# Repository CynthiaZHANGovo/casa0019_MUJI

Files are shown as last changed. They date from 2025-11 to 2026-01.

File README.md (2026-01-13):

# SkySync_Transit

## Description

SkySync_Transit is a hybrid system combining **physical devices** and a **digital twin**, designed specifically to assist **UCL students** in planning their bus trips after classes. The system integrates **bus schedules**, **weather**, **walking times**, and **CE course timetable data** to provide real-time recommendations and visual feedback.

**Motivation:**  
UCL students often need to quickly decide which bus to catch after class based on their course schedule and weather conditions. SkySync_Transit was created to make commuting more intuitive, reducing stress and helping students make informed decisions.

**Why this project:**  
Instead of relying solely on apps or static timetables, SkySync_Transit combines physical interaction, course timetable data, and a digital dashboard, allowing users to instantly see bus recommendations, estimated walking times, and weather conditions tailored to their class schedule.

**Problem it solves:**  
Helps UCL students efficiently plan which bus to take after class, estimate walking times under different weather conditions, and visually understand the urgency of catching the next bus.

**What we learned:**  
- Integration of hardware (sensors, servo, LED, LCD) with APIs and MQTT data streams  
- Visualizing time-sensitive information using both physical pointers and a digital gauge dashboard  
- Combining CE timetable data with real-world commuting decisions  
- Building a digital twin that accurately mirrors physical device behavior  

---

## Table of Contents

- [Overview](#overview)
- [Physical Device](#physical-device)
- [Digital Twin](#digital-twin)
- [Gauge Dashboard Design](#gauge-dashboard-design)
- [Software & Data Interfaces](#software--data-interfaces)
- [Connection](#connection)
- [Usage](#usage)
- [Credits](#credits)
- [GitHub Repository Structure](#github-repository-structure)
- [License](#license)

---

## Overview

SkySync_Transit allows UCL students to select a bus route using a rotary knob. Based on the selected bus, current weather, walking distance, and class schedule, the system calculates estimated travel time, recommends the next best bus, and provides visual feedback through an LCD display, a physical pointer, and LED strip. All data is synced via MQTT and APIs.

---

## Physical Device

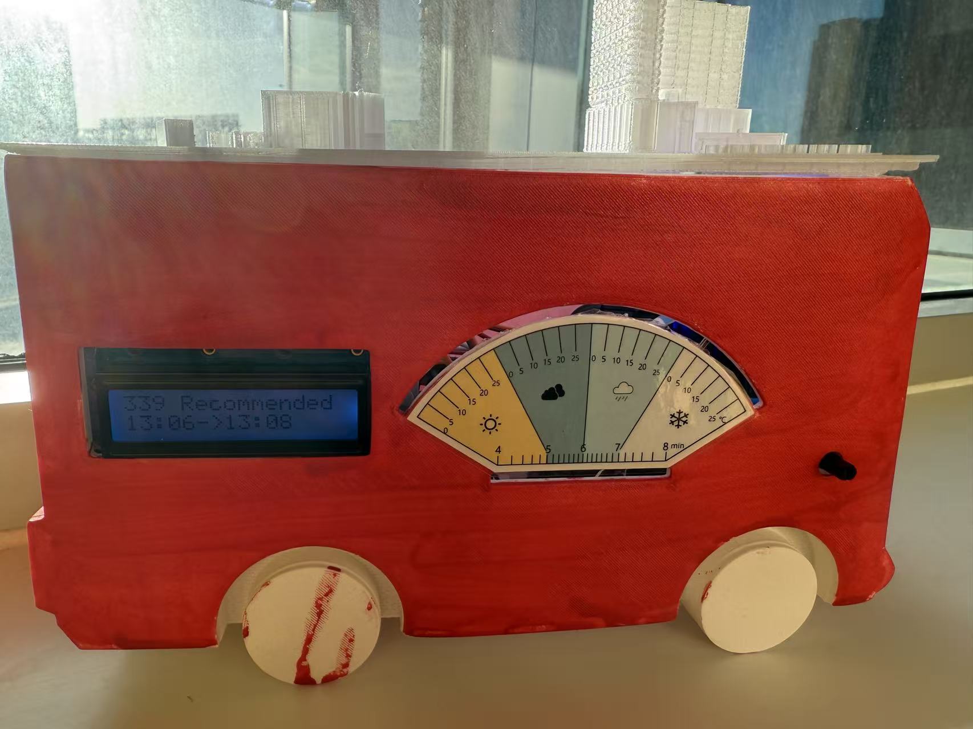
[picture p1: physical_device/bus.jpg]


The physical device provides a tangible, real-time representation of weather conditions, walking time, and bus urgency. It includes:

### Hardware Components

- **ESP8266 Microcontroller**  
  - Core controller for all hardware components  
  - Connects to Wi-Fi to access APIs and MQTT topics  
  - Handles sensor input, servo output, LED control, and data processing  

- **Rotary Angle Sensor v1.2**  
  - Used to select the bus number (108 or 339)  
  - Automatically detected on startup, triggering timetable API requests  

- **MG90S Servo Motor**  
  - Drives the analog-style pointer  
  - Pointer position corresponds to weather condition, temperature segment, and calculated walking time  

- **LCD Display (Grove-LCD RGB Backlight)**  
  - Shows estimated walking time based on weather + temperature  
  - Displays bus timetable returned from the API  
  - Highlights the recommended bus based on UCL CE class schedule  

- **LED Strip (BTF 5V 60LED/m)**  
  - Uses color gradients to visualize urgency of catching the next bus  
  - Updates dynamically based on timetable and walking-time calculations  

- **3D-Printed Structure**  
  - Two-print materials used: opaque + translucent  
  - Represents walking route from One Pool Street to the destination  
  - Houses the gauge instrument panel (print + lamination)

---

## Digital Twin

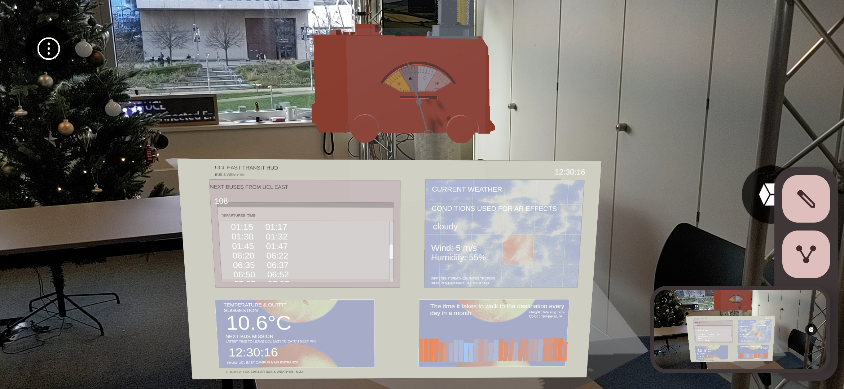
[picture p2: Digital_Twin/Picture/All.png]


The digital twin mirrors the behavior of the physical device and provides **more detailed data**:

- Digital gauge dashboard showing the same segments, zones, and walking-time pointer  
- Displays more bus options than the physical device  
- Shows detailed weather information and suggestions for travel  
- Allows users to **scan different images** to switch between bus lines  
- Provides a richer monitoring interface for debugging and live demonstration  

---

## Gauge Dashboard Design

The **gauge dashboard** is the visual system used both in the physical device and digital twin.

### Zones & Segments

- Weather zones (left → right): **Sunny → Cloudy → Rainy → Snowy**  
- Each zone has **6 temperature segments**:

| Segment | Temperature (°C) |
|---|---|
| 0 | temp ≤ 0 |
| 1 | 0 < temp ≤ 5 |
| 2 | 5 < temp ≤ 10 |
| 3 | 10 < temp ≤ 20 |
| 4 | 20 < temp ≤ 25 |
| 5 | temp > 25 |

- Total walking time range: **4–8 minutes**  
- Each segment = **10 seconds**  
- Example: Rainy + 8.8°C → zone 3, segment 3 → 380 sec → 6.33 minutes  

Both APIs and MQTT provide pre-calculated results:
- Weather  
- Temperature  
- Walking time (seconds + minutes)  
- Zone index  
- Segment index  
- Final pointer target

---

## Software & Data Interfaces

### Bus Timetable API
- **Endpoints**:  
  - `http://10.129.111.26:3000/api/timetable/108`  
  - `http://10.129.111.26:3000/api/timetable/339`  
- Returns full-day schedules for selected bus  
- Includes times for **Aquatic Center** and **Stratford Station**  
- Provides **recommended next bus** based on CE timetable (class ends at 13:00)  
- **MQTT topics** available for live streaming (use lowercase *qingshan*)

### Weather & Walking Time API
- `http://10.129.111.26:3000/api/current-walk`  
- Returns temperature, weather, pointer zone/segment, and walking time  

### CE Course Timetable Integration
- Ensures bus recommendation fits UCL students’ real class schedules  
- The system chooses the next bus *after* class end time

---

## Connection

1. Connect all hardware components.  
2. Connect to the UCL classroom network (required for API access).  
3. Install libraries for sensors, servo, LED strip, LCD display, and MQTT.  
4. Clone the repository to the ESP8266.  
5. Configure MQTT topics (`qingshan/...`).  
6. Power the device to begin automatic detection and data fetching.  

---

## Usage

1. Power on the system.  
2. Select bus route via the rotary knob.  
3. Device fetches timetable via API or MQTT.  
4. Weather and walking data are retrieved from the walking API.  
5. System calculates estimated walking time and bus recommendation.  
6. Data is displayed via LCD, pointer gauge, and LED urgency indicator.  
7. Digital twin shows additional details for debugging or demonstration.
---

## System Flow

Rotary Knob -> Detect Bus Number -> Fetch Bus Timetable (API/MQTT) 
             -> Fetch Weather & Walking Time -> Calculate Estimated Travel Time 
             -> Physical Gauge + LCD + LED Output 
             -> Digital Twin Dashboard Rendering

---

## GitHub Repository Structure

- **[Backend_code_section](https://github.com/CynthiaZHANGovo/casa0019_MUJI/tree/main/Backend_code_section)**  
  Backend APIs for bus timetables, weather data, walking-time calculation, and CE timetable logic.

- **[physical_device](https://github.com/CynthiaZHANGovo/casa0019_MUJI/tree/main/physical_device)**  
  Coding documents of physical device.

- **[Digital_Twin](https://github.com/CynthiaZHANGovo/casa0019_MUJI/tree/main/Digital_Twin)**  
  Files of digital twin.

- **[Scripts](https://github.com/CynthiaZHANGovo/casa0019_MUJI/tree/main/Scripts)**  
  C# scripts for API handling, MQTT communication, gauge animation, and UI logic.

- **[Shell](https://github.com/CynthiaZHANGovo/casa0019_MUJI/tree/main/Shell)**  
  3D-printable files for the physical enclosure and gauge mechanism.

- **[Sensors_Testing](https://github.com/CynthiaZHANGovo/casa0019_MUJI/tree/main/Sensors_Testing)**  
  Sensor testing code and calibration references.

- **[Documents](https://github.com/CynthiaZHANGovo/casa0019_MUJI/tree/main/Documents)**  
  Project notes, meeting minutes, and early design concepts.

---

## Credits

* Project Team Members:

  * [Qingshan Luo](https://github.com/malus-eng)
  * [Xinyi Zhang](https://github.com/CynthiaZHANGovo)
  * [Yidan Gao](https://github.com/gydgzh)
  * [Zihang He](https://github.com/xms12138)

---

## License

This project is licensed under the [MIT License](https://choosealicense.com/licenses/mit/).

---

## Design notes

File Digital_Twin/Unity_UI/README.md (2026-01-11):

# SkySync_Transit

## Work Division Agenda

**Course:** CASA0019: Sensor Data Visualisation (25/26)

**Total length:** \~2000 words (±10%)

---

## 1. Front Page & Administrative Info（≈150 words）

- Project Title: _SkySync_Transit_

- Course name & academic year

- Group members（姓名 + GitHub username）

- GitHub repository link（可访问）

- 简短 project tagline（1–2 句）

---

## 2. Project Context & Motivation

SkySync_Transit was developed for UCL students when making commuting decisions immediately after class. Many students regularly travel to Stratford and surrounding areas using bus services. These decisions are often time-sensitive, as students need to leave shortly after a class ends in order to select an appropriate bus. Missing a bus may lead to additional waiting time or a less efficient journey, particularly during busy periods. This highlights the need for clearer and more immediate representations of travel-related information (Batty, 2013).

The project focuses on the integration of bus timetable data, real-time weather conditions, and walking time estimates, as these factors jointly influence commuting decisions but are rarely considered together in an intuitive manner (Ma et al., 2019). While existing mobile applications provide access to such information, they often require active searching and increased cognitive effort from users, particularly in time-constrained situations (Aliannejadi et al., 2019). SkySync_Transit addresses this gap by combining these datasets into a single, coherent system that supports faster decision-making through visual and physical feedback.

---

## 3. System Overview & Design Concept（≈250 words）

### 3.1 Physical System

The physical part of SkySync_Transit is designed as a self-contained, real-time indicator of travel conditions. An **ESP8266 microcontroller** forms the core of the system, reading inputs from temperature, humidity and gas sensors as well as the rotary angle sensor that selects the active bus route (108 or 339). It connects to Wi-Fi to fetch live timetables and weather data, combines these with local sensor readings, and computes key parameters such as current conditions, estimated walking time and a recommended bus. These values are published via a small set of **MQTT topics**, which are subscribed to by the servo motor, LED strip and LCD display. In this way, the pointer, backlit display and colour-coded LEDs act as an analogue “dashboard” that visualises bus urgency and walking time using the same underlying logic. The physical system is therefore responsible for sensing, decision-making and embodied feedback in the classroom.

### 3.2 Digital Twin System

The digital part of SkySync_Transit is implemented as an AR **digital twin** in Unity. A lightweight backend exposes the same information used by the ESP8266 through RESTful **APIs**, including timetable endpoints for routes 339 and 108 and a `current-walk` style endpoint that wraps the weather-dependent walking-time model. Unity scripts such as `BusAPIManager` and `WeatherAPIManager` call these APIs, deserialize JSON into typed data models, and update the **TransitHubCanvas** interface, which contains panels for “NEXT BUSES FROM UCL EAST”, current weather, temperature and outfit suggestion, and data visualisation. The digital twin mirrors the behaviour of the physical gauge but is easier to modify, scale and debug, for example by testing new layouts or visual encodings without changing the hardware. Together, the MQTT-driven device and API-driven AR interface form a single system where both physical and digital views are always consistent and based on the same data.

---

## 4. Physical Device Design & Implementation

### 4.1 Hardware Design

The physical device of SkySync_Transit provides a tangible, real-time representation of weather conditions, estimated walking time, and bus urgency.
An **ESP8266 microcontroller** is used as the main controller for the system. It connects to Wi-Fi to access external APIs and MQTT topics, processes incoming data, and controls all input and output components, including sensors, the servo motor, LED strip, and LCD display.
User input is handled through a **Rotary Angle Sensor v1.2**, which allows users to select between bus routes (e.g. 108 or 339). The selected route is detected automatically and triggers requests to the corresponding bus timetable API.
A **MG90S servo motor** drives an analog-style pointer on the gauge interface. The pointer position reflects a combination of weather conditions, temperature segments, and calculated walking time, providing a quick visual indication of travel conditions.
A **Grove LCD RGB Backlight display** presents estimated walking time and bus timetable information retrieved from the API, and highlights the recommended bus based on the UCL CE course timetable. In addition, a **BTF 5V LED strip (60 LEDs/m)** visualises the urgency of catching the next bus using colour gradients that update dynamically according to timetable and walking-time calculations.

### 4.2 3D-Printed Structure and Gauge Panel

The 3D-printed structure has two main parts. The **transparent top** allows the LED strip to display the walking route to the destination, and incorporates a model of **One Pool Street**, combined with site data adapted from **CADMAPPER**, to ensure spatial accuracy. The second part is a custom-built model of a **classic London bus**, painted in red, which serves as a tangible reference for the selected bus route. The opaque base was designed with consideration for **sensor placement and component relationships**, ensuring stable integration of the hardware.

The **gauge instrument panel** is integrated into this structure, combining printed graphics and lamination to create a clear and durable interface. It visualizes estimated walking time using a combination of weather zones—Sunny, Cloudy, Rainy, and Snowy—and corresponding temperature segments. A servo-driven pointer, LED strip, and LCD display work together to convey time-sensitive information intuitively, allowing users to quickly perceive walking time and bus urgency. For example, Rainy conditions at 8.8°C correspond to a moderate walking time of approximately 6.33 minutes.

### 4.3 Data Visualisation Logic (Physical)

The rotary angle sensor is wired to the ESP8266’s A0, where its ratiometric voltage output is sampled and converted into discrete control state. The Grove RGB LCD shares the controller’s I²C bus (SDA/SCL), while enabling dual control of text and backlight through the same serial channel. The MG90S servo is attached to a PWM-capable pin so that duty-cycle modulation directly defines its mechanical output angle. 

The WS2812 LED strip is driven from a single digital pin with microsecond-scale timing accuracy. Because Wi-Fi, MQTT parsing and GPIO servicing run concurrently on the ESP8266, update jitter is mitigated by sequencing LED writes against network activity. 

The pointer is driven by an MG90S micro servo controlled by the ESP8266. Real-time weather and temperature data are first processed in the backend and discretised into **24 weather–temperature zones** on the dial (from sunny and mild on the left to snowy and harsh on the right). The backend sends the index of the active zone as an integer `segmentIndex` via MQTT.

On the physical gauge, only the calibrated arc between approximately **33° and 147°** is used. However, the firmware positions the pointer at the centre of each zone rather than at the boundary, producing a smoother, more readable pointer distribution. This 114° span is divided into 24 equal zones, and the pointer is positioned at the **centre of each zone**, which yields an effective step of about **4.25° per segment**. This mapping is hard-coded in the firmware as: 

                                                            **angle = 180° − 4.25° × segmentIndex.**

After clamping the result to the physical dial range, the ESP8266 outputs the corresponding PWM signal to the MG90S, moving the pointer cleanly to the selected weather–temperature region. Furthermore, each pointer movement first returns to the leftmost position before repositioning. So in the end, we obtained such a complete physical model.

UI

## 5. Digital Twin & Dashboard Design（≈300 words）

## 5.1 Digital Twin Interface

The SkySync_Transit digital twin is implemented in Unity as an AR screen based on a **World Space Canvas**. The main UI root, **TransitHubCanvas**, follows a layout first prototyped in Figma, with four panels: “NEXT BUSES FROM UCL EAST”, a temperature and outfit suggestion panel, a current weather panel, and a reserved data-visualisation area. During early development, random values were injected into these panels to test bindings and interactions before the real APIs were connected. 

Live data is then provided by “BusAPIManager” and ”WeatherAPIManager“, which call the timetable and current-walk style endpoints, deserialize the JSON into typed models (from APIDataModels), and update TextMeshPro fields in the bus, temperature and weather panels. 

To support both routes within one interface, “MainContent” contains two structurally identical bus panels, **`BusPane339`** and **`BusPane108`**, which share the same layout but are bound to different timetable data. Weather and temperature modules remain permanently active, while simple visibility logic switches between the two bus panels so that scanning 339 or 108 selects the corresponding route without duplicating the rest of the UI. 

## 5.2 Physical Device Synchronisation & Deployment

 To match the physical device and avoid overwhelming the camera view, the ”TransitHubCanvas“ Rect Transform is uniformly scaled down (e.g. all axes ≈ 0.0005), keeping proportions consistent in AR , and ARCore enabled in XR Plug-in Management, allowing the digital twin to run on Android phones alongside the hardware system.

## 5.3 Image Recognition

 Image recognition is implemented with AR Foundation. A reference image library, “BusRoutesImageLibrary”, stores the printed markers **`QR_339`** and **`QR_108`** with their physical sizes and is assigned to “ARTrackedImageManager” on the XR Origin. A dedicated controller, “BusQRImageController”, listens to “trackedImagesChanged”, positions and rotates “TransitHubCanvas” so that the UI stands upright and floats slightly in front of the detected marker, and then toggles BusPane339 or BusPane108 based on “referenceImage.name”, while leaving the weather and temperature panels unchanged.

## 5.4 Data synchronization and rendering

We use MQTT to fetch backend data, with the lower HUD panel driven entirely by real-time streams to stay synced with the physical system. The system subscribes to three topics — current weather and travel advice, route-specific bus recommendations, and ~30 days of walking-history data. Payloads are received through an M2MQTT client, parsed into strongly typed objects via JsonUtility, and safely handed off to the Unity main thread using simple state flags, since MQTT callbacks execute in the background.

To provide long-term insight rather than momentary status, the data-visualisation panel procedurally generates UI elements at runtime. A bar-chart system instantiates prefabs, scales them according to walking duration, and interpolates colour based on average temperature, converting raw telemetry into compact visual patterns.

Text-based displays are equally data-driven. The bus timetable now uses a three-column format (London Aquatics → Stratford City → recommendation), improving readability without modifying the source format. All UI panels refresh through event-driven logic so that each JSON packet actively updates the interface in real time rather than merely replacing placeholder values.

## 5.5 Realization of the Augmented 3D Digital Twin Model

Digital twins are not only reflected in the interface data layer but also achieved by placing a corresponding 3D bus model in the AR environment. The vehicle's onboard model from the physical device is imported into Unity as a prefab and acts as a child object of the detected QR code image. It automatically inherits the QR code's spatial position and orientation, thus appearing as a fixed object in the real-world scene and moving naturally with the user's viewpoint.

This virtual model is dynamically driven by real-time MQTT data. Unity subscribes to walking status topics and parses messages, extracting the segmentIndex and mapping it to a specific angle to control the rotation of the instrument panel pointer. The control script records the model's basic posture and overlays calculated offsets to ensure the animation is always geometrically aligned with the model. Pointer movement is smoothed using interpolation to avoid jumps and present continuous, natural state changes. We use the same dashboard as the physical system to ensure the pointer's position in the AR scene is consistent with the physical system.

This process forms a real-time feedback loop. When data is updated on the MQTT server, the pointer on the bus in the AR environment is updated simultaneously, allowing users to intuitively perceive changes in external information within the AR scene. By binding the model to an image target, scaling it appropriately, and performing simple visual customizations, we have constructed such a complete digital twin.

UI

---

## 6. Software, Data & Technologies

The data transmission portion of this project primarily relies on the MQTT protocol to transmit signals to the assembled electronic devices and on the API to transmit data to the digital twin system. The project mainly established three MQTT topics for devices to subscribe to: the timetables for bus routes 339 and 108, and the current London temperature and estimated walking time to the station. The API also provides the same three types of data. Using these three datasets, the digital twin and devices can effectively acquire data and display it clearly and efficiently.

More precisely, the data in the project mainly comes from publicly available data on authoritative websites. The timetable information for bus routes 339 and 108 is entirely sourced from the TFL website. Additionally, the London weather and temperature information is obtained from the Open-Meteo website, ensuring overall accuracy and reliability (Paudyal, Shakya and Upadhayaya, 2025). The data printed in this project is formatted as shown in the image below.
<p align="center">
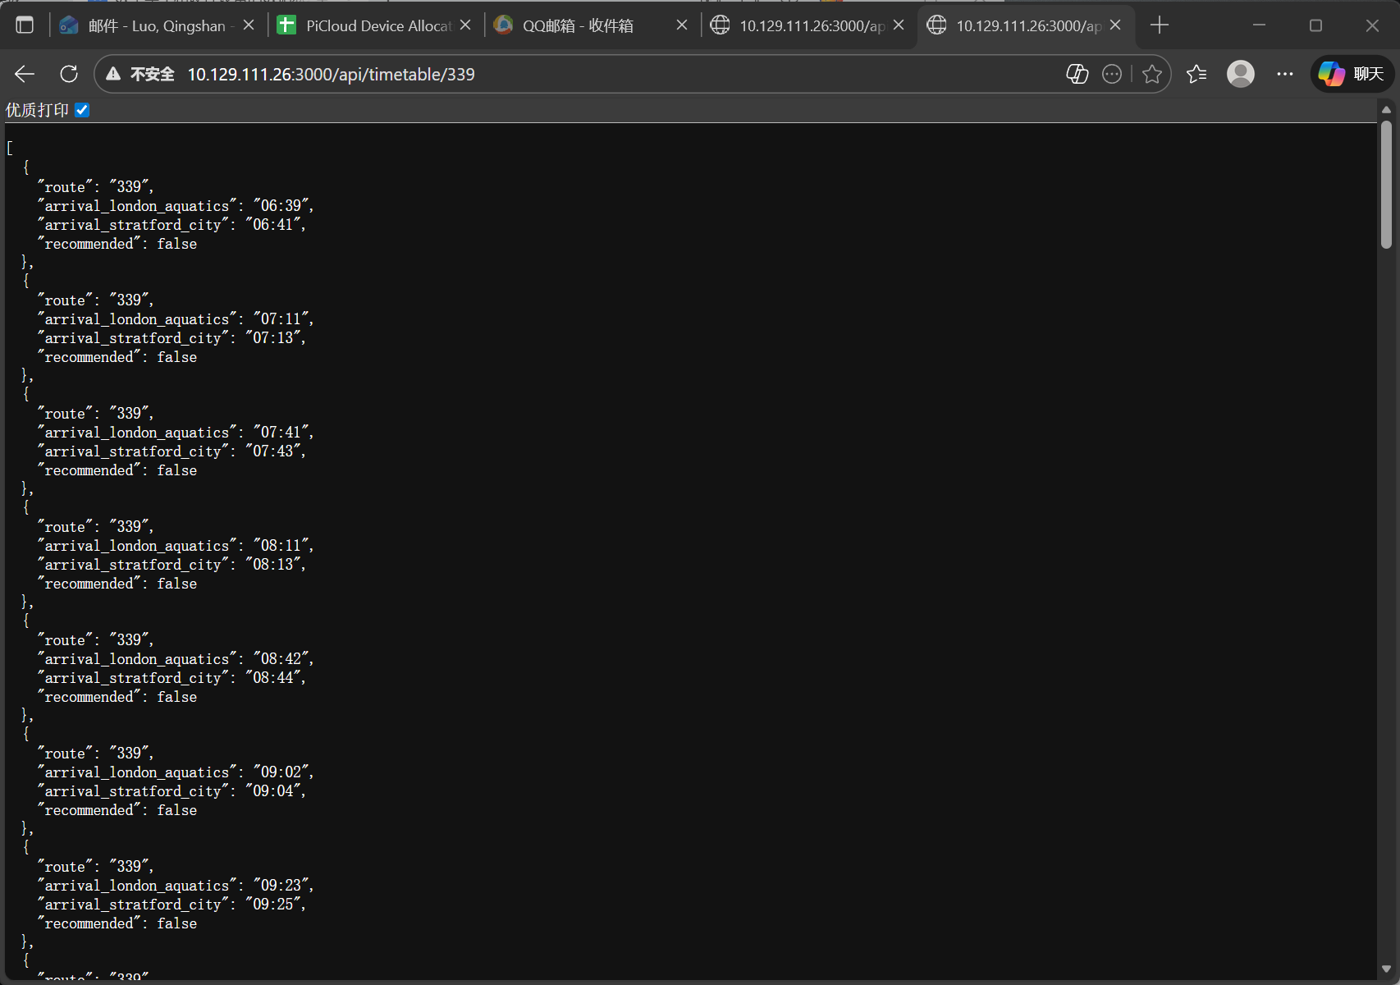
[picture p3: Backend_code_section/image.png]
  
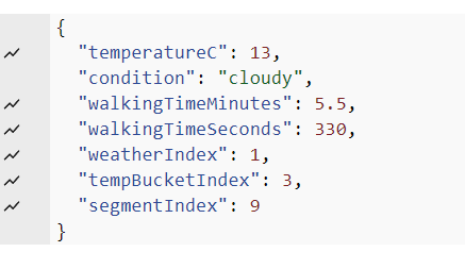
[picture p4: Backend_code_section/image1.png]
  
</p>

For timetables, the first line prints the bus number for easy identification during calls. The second and third lines print the arrival times at London Aquatics and Stratford City stations, respectively. The fourth line indicates whether the bus is recommended. This line helps users choose recommended buses. The project combines the daily class dismissal times and student arrival times at the station to calculate which bus will arrive first after students reach the station and recommends that bus.

For weather-related MQTT topics and APIs, the first line prints the current temperature in London. The second line prints the current weather in London. The third and fourth lines print the walking time from the school to the station in minutes and seconds, respectively. This time is mainly determined by a specific formula based on the current weather and temperature (Dunn, Shaw and Trousdale, 2012). Lines five, six, and seven mainly guide the pointer movement to accurately indicate the estimated time.

### 6.3 Tools & Platforms

**Arduino / ESP8266** serves as the core controller for the physical device, handling sensor inputs, LED and servo outputs, and communication with APIs and the MQTT broker.  

- Unity / dashboard tools

- GitHub as documentation & reproducibility platform

---

## 7. Contributions（≈200 words）

-        *   Hardware & electronics

         *   Software & API integration

         *   Digital twin & UI

         *   Fabrication & physical design

         *   Documentation & GitHub management

***

## 8. What Worked & What Didn’t & Future Improvements

Overall, the project largely achieved its initial goals. The team enabled students to visually see the bus schedules they should take after class, use a pointer to determine the current weather and estimated travel time, and select specific bus routes using a knob. 

However, some goals were not achieved. Initially, the team planned to display all bus information on the hardware in a scrolling display, but they discovered that the processor's storage was insufficient to load the entire schedule, forcing them to abandon this feature (Hercog et al., 2023). Furthermore, the box's structure hindered the display of current weather and walking time. Firstly, the box itself was not large enough while the pointer was slightly long, causing it to touch the left wall of the box when pointing to the far left. Secondly, the pointer was designed inside the box, requiring a slot to be clearly visible, which was inconvenient, making it difficult for users to clearly observe the pointer's direction most of the time. 

To address these shortcomings, future updates to the project will focus on two aspects: firstly, using a more powerful processor with more storage to ensure the display of the entire timetable and more other data. In addition, the team will also consider redesigning the entire box structure to ensure that the box structure itself does not conflict with the pointer's path, or designing the pointer as an external structure to ensure that users can clearly observe the pointer's position.

## 10. Repository Structure & Reproducibility（≈150 words）

- GitHub repo 结构说明

- Code / Unity / STL / diagrams

- How to reproduce the project

- Reference & citation strategy

---

## 11. Conclusion（≈100 words）

- 项目价值总结

- 与 CASA0019 learning outcomes 对应

- Physical data visualisation 的意义

## References

Aliannejadi, M., Harvey, M., Costa, L., Pointon, M. and Crestani, F. (2019) ‘Understanding mobile search task relevance and user behaviour in context’, in *Proceedings of the 2019 Conference on Human Information Interaction and Retrieval*. New York: ACM, pp. 143–151. https://doi.org/10.1145/3295750.3298953

Batty, M. (2013) *The new science of cities*. Cambridge, MA: MIT Press.

Dunn, R. A., Shaw, W. D. and Trousdale, M. A. (2012) ‘The effect of weather on walking behavior in older adults’, *Journal of Aging and Physical Activity*, 20(1), pp. 80–92.

Hercog, D., Zivkovic, M., Belanovic, I., Donlagic, D. and Gams, M. (2023) ‘Design and implementation of ESP32-based IoT devices’, *Sensors*, 23(15), p. 6739. https://doi.org/10.3390/s23156739

Ma, J., Chan, J., Ristanoski, G., Rajasegarar, S. and Leckie, C. (2019) ‘Bus travel time prediction with real-time traffic information’, *Transportation Research Part C: Emerging Technologies*, 105, pp. 536–549. https://doi.org/10.1016/j.trc.2019.06.015

Paudyal, K. R., Shakya, R. and Upadhayaya, J. (2025) ‘Spatiotemporal PM2.5 estimation in Kathmandu using deep learning with OpenMeteo and NASA MERRA-2 data: Performance benchmarking against a machine learning model’, *International Journal on Engineering Technology*, 3(1), pp. 36–45.

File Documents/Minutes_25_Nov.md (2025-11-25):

# Meeting Minutes  – Transport
**Date:** 25-Nov-2025  

## 1. Theme & Overall Idea

- We decided to go with the **Transport** theme.
- After chatting with **Andy** and **Valerio**, the plan is:

  - Use a **timetable API** (bus/train/car) + **weather API**.  
  - Consider **walking time** from **UCL East campus → tube station**.  
  - Combine with the **course timetable** so the system:
    - Knows **when class ends**.
    - Suggests the **best departure** and **a couple of alternatives** before/after.
  - “Highlight” idea:  
    - Use **weather** (rain, wind, etc.) to adjust how long it takes to walk from campus to the station.  
    - Visualise this nicely (both physically and digitally).

---

## 2. Physical Device

The physical device will **visualise vehicle timetables**. Planned components:

- **Vehicle model box**
  - A physical model representing the bus

- **Gear motor + progress bar**
  - A mechanical progress bar driven by a motor, showing journey progress.

- **Simple LED display**
  - Displays key info like:
    - Weather info 
    - Route / line chose
    - Minutes left
    - ...

- **Route switch button**
  - Press to switch between routes (different lines).

---

## 3. Digital Twin

We’ll have **two main 2D screens**:

1. **Weather screen**
   - Shows:
     - Temperature  
     - Rainfall level  
     - UV index  
     - Wind strength
     - ...
   - Also gives simple suggestions like:
     - “Bring an umbrella.”  
     - “Wear a coat.”  
     - “Windy – leave a bit earlier.”

2. **Timetable and journey panel**
   - Displays:
     - Class end time  
     - Relevant transport line(s)  
     - Estimated time needed to walk from UCL East campus to the tube station (adjusted by weather)  
     - The **best** departure option and **alternative options** (earlier and later services)  
   - If time allows, this panel may be enhanced with the **MapBox** to visualise the route and position.

---

## 4. Work Distribution For This Week

- **Yidan Gao**  
  - Build a basic **Unity** setup for the digital twin (two panels: weather + timetable).

- **Qingshan Luo**  
  - Try using **MKR1010 WiFi** to connect to the **timetable API** and **weather API**.

- **Zihang He & Xinyi Zhang**  
  - Build the **gear motor–driven progress bar** for the physical device.

---

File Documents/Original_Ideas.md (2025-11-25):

| Theme | Possible angles | Physical device | Digital twin |
|---|---|---|---|
| Plant wellbeing / digital gardener | - Monitor temperature, soil moisture, CO₂, light level<br>- Publish raw sensor values and derived metrics over MQTT | - LED ring (colour encodes type of issue)<br>- Servo-driven base shell<br>- Small LED display screen or analogue-style gauge | - Time-series chart component<br>- UI gauge for key metrics<br>- Optional 3D plant model<br>- Overall health scale and leaf colour<br>- Toggle which metric the chart displays (same as device controls) |
| Transports | - Vehicle timetable (bus / train) combined with weather API<br>- Include walking time to the station<br>- Provide alternative route options<br>- Integrate with course timetable (e.g. UCL → tube station, CE timetable)<br>- Visualise vehicle times with a light-up model | - Small physical route model with LEDs indicating next departures and routes | - Two main panels: (1) weather information, (2) timetable information<br>- Visualisation of the journey from CELAB → Stratford<br>- (If time) map-based view (e.g. MapBox-style map) |
| Healthcare (Fitness / Rehab game) | - Exercises: squats, walking, jump-rope, hand swings<br>- Provide calorie and other feedback<br>- Use BMI, pulse, and limb motion (ankle / wrist / hand)<br>- Estimate calories from time + user input (height / weight) + orientation / motion sensors | - Battledore / wand-like device<br>- Worn on ankle / wrist / hand to track motion<br>- LEDs for feedback (e.g. success, intensity, rhythm, heart-rate zone cue) | - AR avatar or pet reacting to the user’s motion and performance (e.g. cheering, growing, changing appearance based on activity and adherence) |

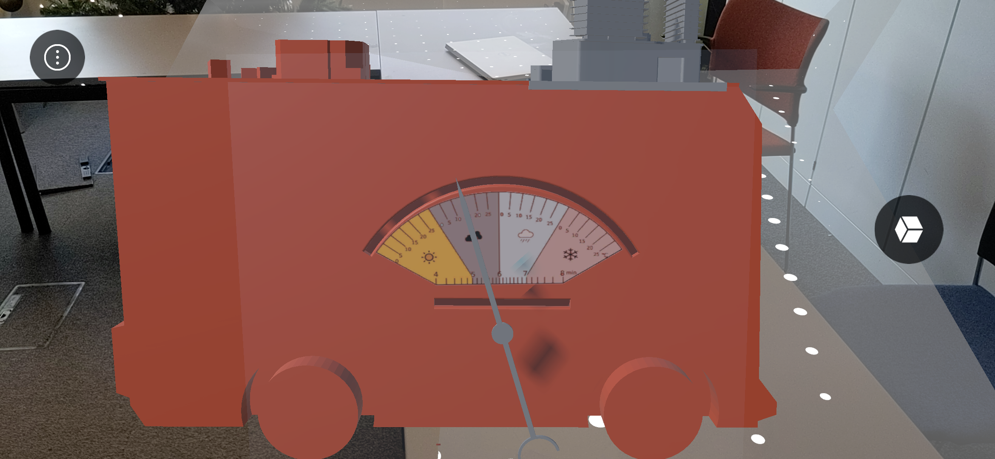
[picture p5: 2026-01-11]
Digital_Twin/Picture/Bus.png

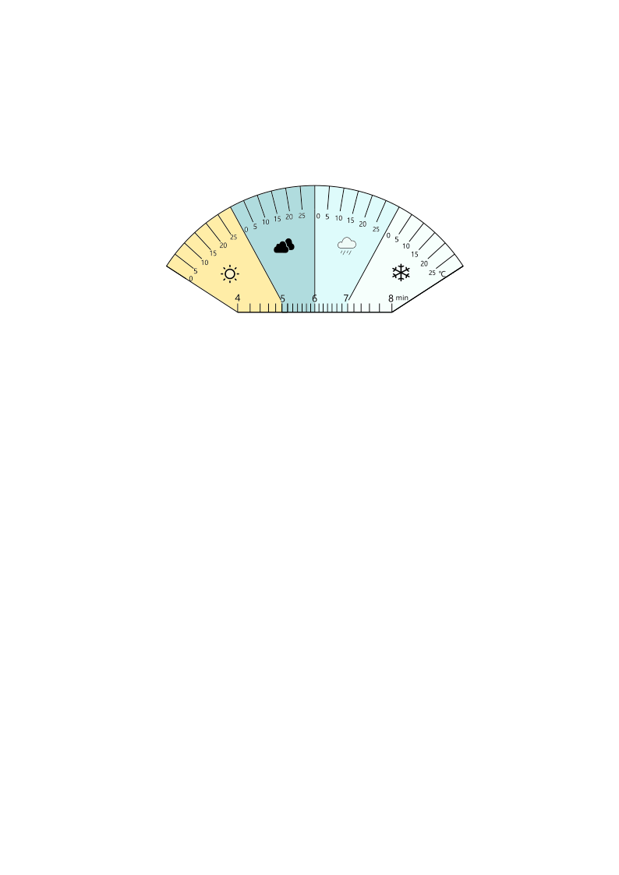
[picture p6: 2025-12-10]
Digital_Twin/Model/gauge.png

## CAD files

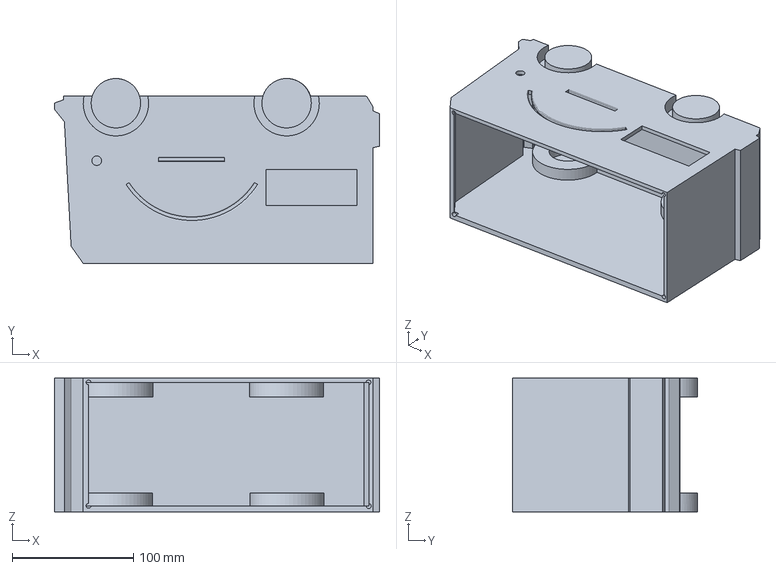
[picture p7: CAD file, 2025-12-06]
physical_device/Shell/car Model.3mf
268.4 x 152.8 x 110.7 mm

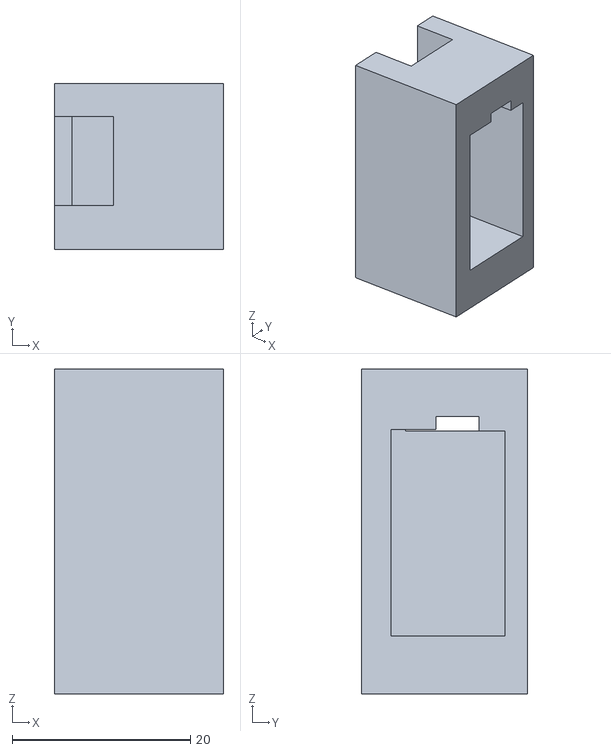
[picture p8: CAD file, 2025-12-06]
physical_device/Shell/ServoHolder2.0.stl
19.0 x 18.6 x 36.5

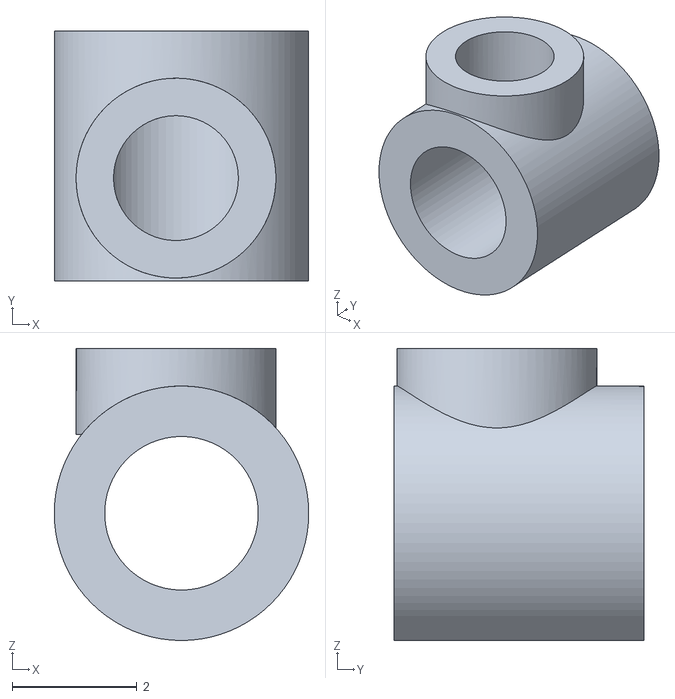
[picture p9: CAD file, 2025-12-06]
physical_device/Shell/ring3.0.stl
4.08 x 4.00 x 4.68

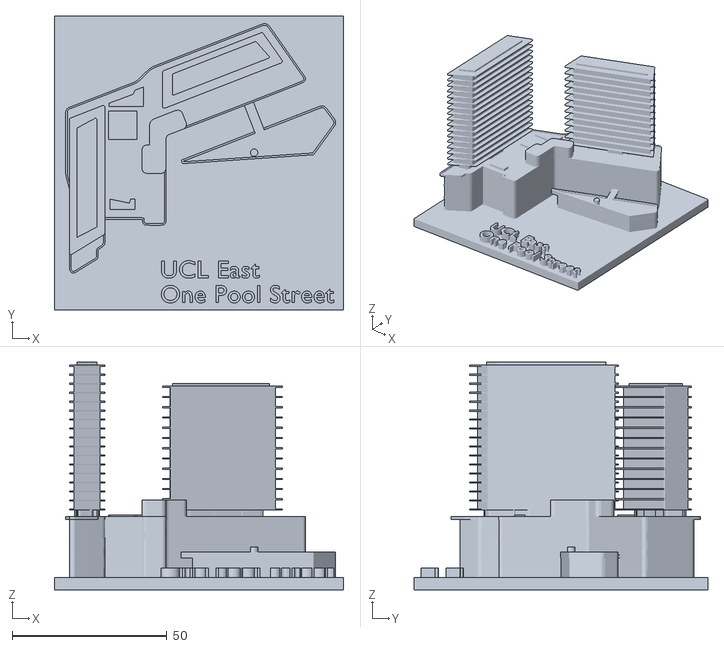
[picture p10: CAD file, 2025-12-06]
physical_device/Shell/OPS (1).stl
93.5 x 95.1 x 73.6

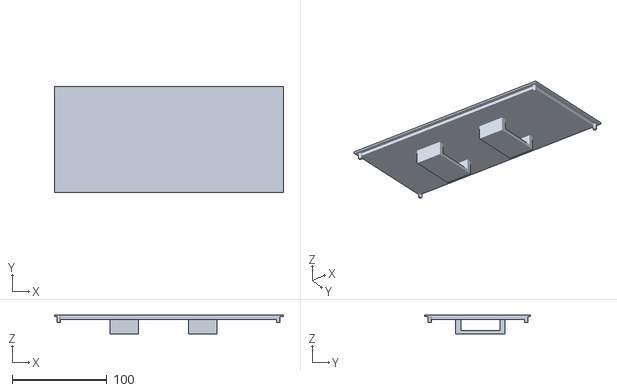
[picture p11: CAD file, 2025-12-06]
physical_device/Shell/Cover.stl
241.1 x 111.1 x 19.5

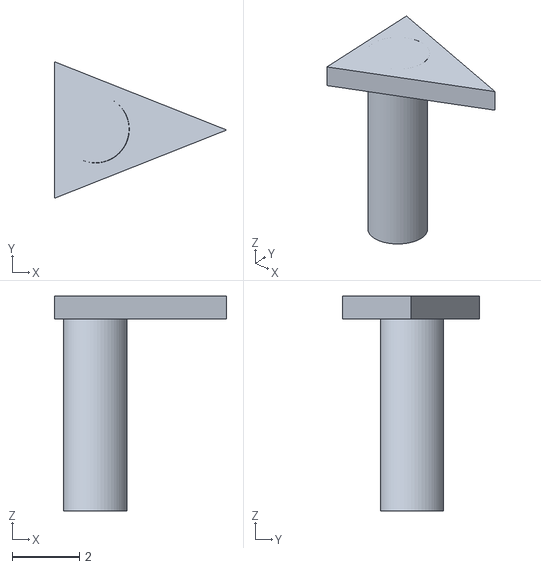
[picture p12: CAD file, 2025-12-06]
physical_device/Shell/mark2.0.stl
5.11 x 4.06 x 6.38

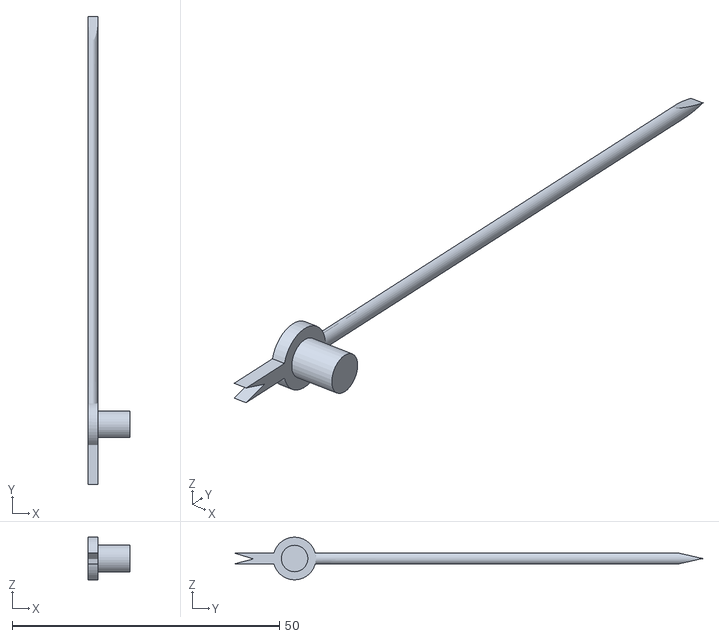
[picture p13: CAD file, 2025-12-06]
physical_device/Shell/PointerTest.stl
7.80 x 87.6 x 8.00

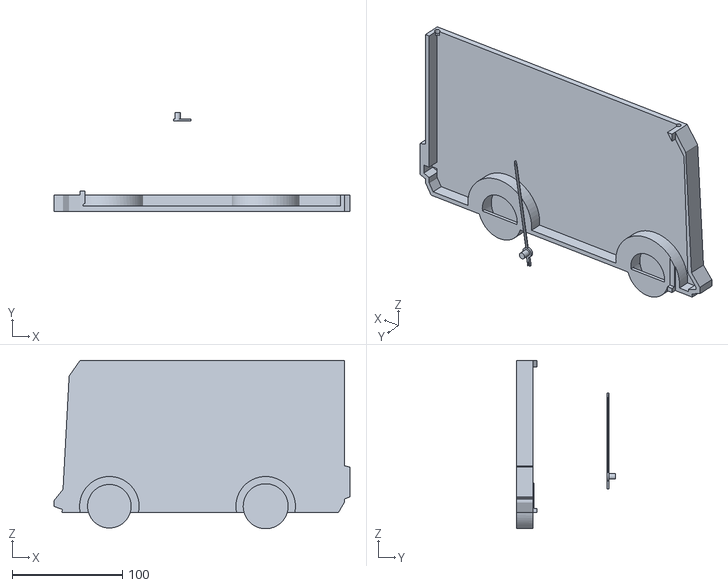
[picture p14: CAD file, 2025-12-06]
physical_device/Shell/carModel_Fix2.0.stl
268.4 x 89.6 x 152.7

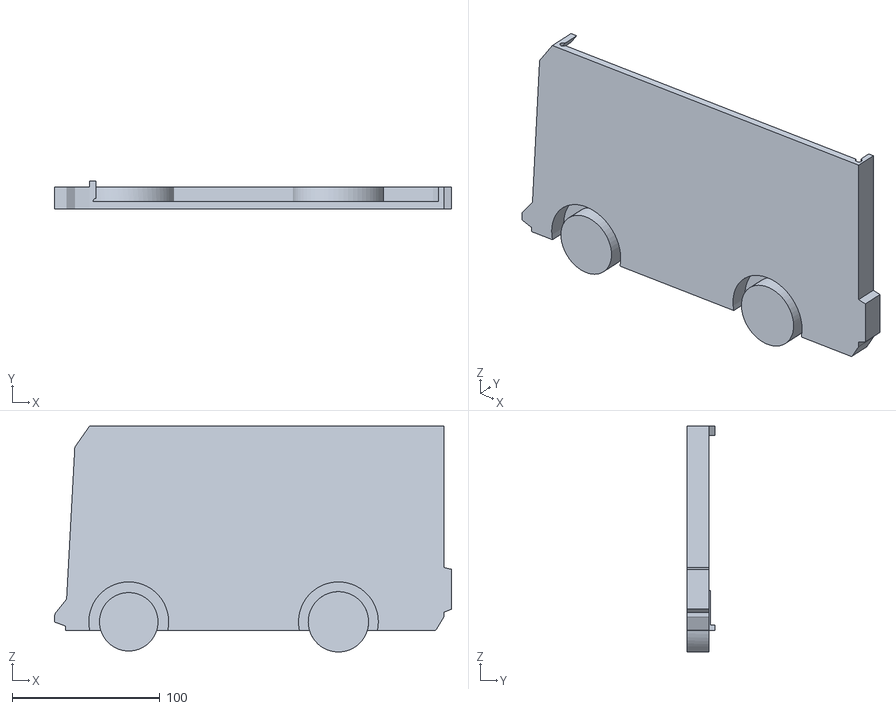
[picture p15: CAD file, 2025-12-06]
physical_device/Shell/Fix.stl
268.4 x 18.7 x 152.7

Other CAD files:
Digital_Twin/Model/DigitalCar.blend

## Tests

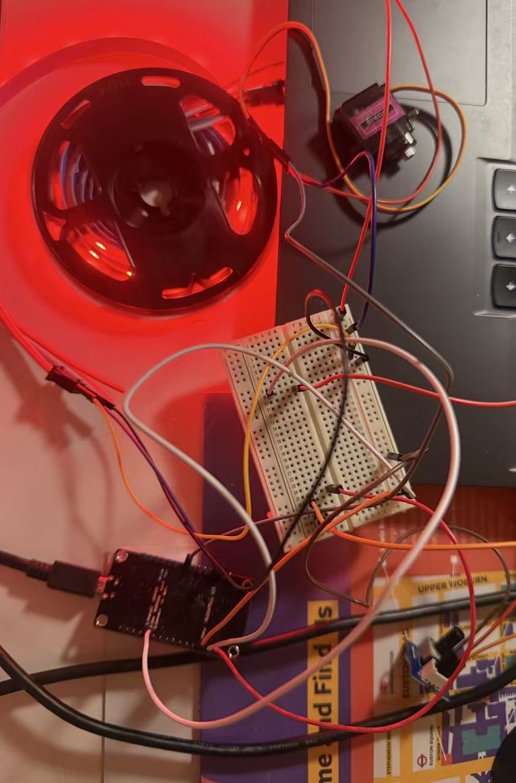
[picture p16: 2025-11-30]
physical_device/Sensors_Testing/SensorsTesting.jpg

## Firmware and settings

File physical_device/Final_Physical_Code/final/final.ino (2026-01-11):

#include <ESP8266WiFi.h>
#include <PubSubClient.h>
#include <Wire.h>
#include <rgb_lcd.h>
#include <ArduinoJson.h>
#include <Servo.h>          // Servo
#include <Adafruit_NeoPixel.h>  // WS2812 / WS2812B

// ================== WiFi config ==================
const char* ssid     = "CE-Hub-Student";
const char* wifiPass = "casa-ce-gagarin-public-service";

// ================== MQTT config ==================
const char* mqttServer  = "mqtt.cetools.org";
const int   mqttPort    = 1884;
const char* mqttUser    = "student";
const char* mqttPass    = "ce2021-mqtt-forget-whale";

const char* topicBus108 = "student/MUJI/qingshan/bus-108-mini";
const char* topicBus339 = "student/MUJI/qingshan/bus-339-mini";
const char* topicWalk   = "student/MUJI/qingshan/walk";

// ================== hardware pins ==================
const int ROTARY_PIN = A0;   // Grove Rotary Angle sensor to A0
const int SERVO_PIN  = D5;   // MG90S to D5
const int LED_PIN    = D4;   // WS2812 strip data pin
const int NUM_LEDS   = 14;   // first 25 LEDs

// ================== Grove LCD ==================
rgb_lcd lcd;

// ================== MQTT objects ==================
WiFiClient espClient;
PubSubClient client(espClient);

// ================== Servo ==================
Servo curtainServo;
int   currentServoAngle = 0;

// ================== WS2812 strip ==================
Adafruit_NeoPixel strip(NUM_LEDS, LED_PIN, NEO_GRB + NEO_KHZ800);

// ================== data structures ==================
struct BusInfo {
  String route;
  String londonAquatics;   // arrival_london_aquatics
  String stratfordCity;    // arrival_stratford_city
  bool   valid;
  bool   recommended;
};

BusInfo bus108Rec;   // 108: recommended
BusInfo bus108Next;  // 108: next
bool    hasBus108 = false;

BusInfo bus339Rec;   // 339: recommended
BusInfo bus339Next;  // 339: next
bool    hasBus339 = false;

// current zone: 0=108, 1=339
int currentZone = 0;
int lastZone    = -1;
bool displayDirty = true;

// ================== helpers ==================

String trim16(const String &s) {
  if (s.length() <= 16) return s;
  return s.substring(0, 16);
}

String makeLine(const BusInfo &b, bool highlight) {
  if (!b.valid) {
    return highlight ? ">No data" : " No data";
  }

  String line = b.route + " " + b.londonAquatics + " " + b.stratfordCity;
  if (highlight) {
    line = ">" + line;
  } else {
    line = " " + line;
  }
  return trim16(line);
}

void renderDisplay() {
  lcd.clear();

  BusInfo *b = nullptr;

  if (currentZone == 0) {
    if (!hasBus108 || !bus108Rec.valid) {
      lcd.setCursor(0, 0);
      lcd.print(trim16("Waiting 108"));
      lcd.setCursor(0, 1);
      lcd.print("");
      return;
    }
    b = &bus108Rec;
  } else {
    if (!hasBus339 || !bus339Rec.valid) {
      lcd.setCursor(0, 0);
      lcd.print(trim16("Waiting 339"));
      lcd.setCursor(0, 1);
      lcd.print("");
      return;
    }
    b = &bus339Rec;
  }

  String line1 = b->route + " Recommended";
  lcd.setCursor(0, 0);
  lcd.print(trim16(line1));

  String line2 = b->londonAquatics + "->" + b->stratfordCity;
  lcd.setCursor(0, 1);
  lcd.print(trim16(line2));
}

void updateZoneFromRotary() {
  int raw = analogRead(ROTARY_PIN);  // 0~1023
  int zone = (raw < 512) ? 0 : 1;    // 0:108, 1:339

  currentZone = zone;

  if (zone != lastZone) {
    lastZone = zone;
    displayDirty = true;
    Serial.print("Zone changed to: ");
    Serial.println(zone == 0 ? "108" : "339");
  }
}

// ================== WiFi & MQTT ==================
void setupWiFi() {
  delay(10);
  Serial.println();
  Serial.print("Connecting to ");
  Serial.println(ssid);

  WiFi.mode(WIFI_STA);
  WiFi.begin(ssid, wifiPass);

  while (WiFi.status() != WL_CONNECTED) {
    delay(500);
    Serial.print(".");
  }

  Serial.println();
  Serial.print("WiFi connected, IP: ");
  Serial.println(WiFi.localIP());
}

// ================== JSON helpers ==================
bool extractRecommendedAndNextObjects(const String& jsonStr,
                                      String& recObjJson,
                                      String& nextObjJson) {
  recObjJson  = "";
  nextObjJson = "";

  int recPos = jsonStr.indexOf("\"recommended\":true");
  int recStart, recEnd;

  if (recPos != -1) {
    recStart = jsonStr.lastIndexOf('{', recPos);
    recEnd   = jsonStr.indexOf('}', recPos);
  } else {
    recStart = jsonStr.indexOf('{');
    if (recStart == -1) return false;
    recEnd = jsonStr.indexOf('}', recStart);
  }

  if (recStart == -1 || recEnd == -1) {
    return false;
  }

  recObjJson = jsonStr.substring(recStart, recEnd + 1);

  int nextStart = jsonStr.indexOf('{', recEnd + 1);
  if (nextStart != -1) {
    int nextEnd = jsonStr.indexOf('}', nextStart);
    if (nextEnd != -1) {
      nextObjJson = jsonStr.substring(nextStart, nextEnd + 1);
    }
  }

  return true;
}

void parseBusJson(const char* topic, const String& jsonStr) {
  String recObjJson;
  String nextObjJson;

  if (!extractRecommendedAndNextObjects(jsonStr, recObjJson, nextObjJson)) {
    Serial.println("Failed to extract objects from JSON string.");
    return;
  }

  Serial.println("Recommended Obj JSON:");
  Serial.println(recObjJson);
  if (nextObjJson.length() > 0) {
    Serial.println("Next Obj JSON:");
    Serial.println(nextObjJson);
  }

  BusInfo recBus;
  BusInfo nextBus;
  recBus.valid  = false;
  nextBus.valid = false;

  {
    StaticJsonDocument<256> doc;
    DeserializationError err = deserializeJson(doc, recObjJson);
    if (err) {
      Serial.print("JSON parse error (recommended): ");
      Serial.println(err.c_str());
    } else {
      recBus.route          = String((const char*)doc["route"]);
      recBus.londonAquatics = String((const char*)doc["arrival_london_aquatics"]);
      recBus.stratfordCity  = String((const char*)doc["arrival_stratford_city"]);
      recBus.valid          = true;
      recBus.recommended    = doc["recommended"] | true;
    }
  }

  if (nextObjJson.length() > 0) {
    StaticJsonDocument<256> docNext;
    DeserializationError err = deserializeJson(docNext, nextObjJson);
    if (err) {
      Serial.print("JSON parse error (next): ");
      Serial.println(err.c_str());
    } else {
      nextBus.route          = String((const char*)docNext["route"]);
      nextBus.londonAquatics = String((const char*)docNext["arrival_london_aquatics"]);
      nextBus.stratfordCity  = String((const char*)docNext["arrival_stratford_city"]);
      nextBus.valid          = true;
      nextBus.recommended    = docNext["recommended"] | false;
    }
  }

  if (!recBus.valid) {
    Serial.println("No valid recommended bus parsed.");
    return;
  }

  String t = String(topic);
  if (t == topicBus108) {
    bus108Rec  = recBus;
    bus108Next = nextBus;
    hasBus108  = true;
    Serial.println("✅ Updated data for 108");
  } else if (t == topicBus339) {
    bus339Rec  = recBus;
    bus339Next = nextBus;
    hasBus339  = true;
    Serial.println("✅ Updated data for 339");
  }

  displayDirty = true;
}

// ========== parse walk JSON and control servo ==========
void parseWalkJson(const String& jsonStr) {
  StaticJsonDocument<256> doc;
  DeserializationError err = deserializeJson(doc, jsonStr);

  if (err) {
    Serial.print("JSON parse error (walk): ");
    Serial.println(err.c_str());
    return;
  }

  int segmentIndex = doc["segmentIndex"] | 0;
  Serial.print("segmentIndex = ");
  Serial.println(segmentIndex);

  float rawAngle = 180.0f - 4.25f * segmentIndex;
  if (rawAngle < 0)   rawAngle = 0;
  if (rawAngle > 180) rawAngle = 180;

  int targetAngle = (int)(rawAngle + 0.5f);

  Serial.print("Move servo from 180 to ");
  Serial.print(targetAngle);
  Serial.println(" deg");

  curtainServo.write(180);
  delay(300);
  curtainServo.write(targetAngle);
  currentServoAngle = targetAngle;
}

// ================== MQTT callback ==================
void mqttCallback(char* topic, byte* payload, unsigned int length) {
  Serial.print("Message arrived [");
  Serial.print(topic);
  Serial.println("]");

  String msg;
  msg.reserve(length + 1);
  for (unsigned int i = 0; i < length; i++) {
    msg += (char)payload[i];
  }

  Serial.println("---- Raw JSON ----");
  Serial.println(msg);
  Serial.println("------------------");

  String t = String(topic);

  if (t == topicBus108 || t == topicBus339) {
    parseBusJson(topic, msg);
  } else if (t == topicWalk) {
    parseWalkJson(msg);
  } else {
    Serial.println("Ignoring topic.");
  }
}

// ================== MQTT connect ==================
void reconnectMQTT() {
  while (!client.connected()) {
    Serial.print("Attempting MQTT connection...");
    String clientId = "ESP8266-BUS-";
    clientId += String(ESP.getChipId(), HEX);

    if (client.connect(clientId.c_str(), mqttUser, mqttPass)) {
      Serial.println("connected");

      client.subscribe(topicBus108);
      client.subscribe(topicBus339);
      client.subscribe(topicWalk);

      Serial.print("Subscribed to: ");
      Serial.println(topicBus108);
      Serial.print("Subscribed to: ");
      Serial.println(topicBus339);
      Serial.print("Subscribed to: ");
      Serial.println(topicWalk);

      lcd.clear();
      lcd.setCursor(0, 0);
      lcd.print("MQTT connected");
      lcd.setCursor(0, 1);
      lcd.print("108&339&walk");

      displayDirty = true;

    } else {
      Serial.print("failed, rc=");
      Serial.print(client.state());
      Serial.println(" try again in 5 seconds");

      lcd.clear();
      lcd.setCursor(0, 0);
      lcd.print("MQTT fail rc ");
      lcd.print(client.state());
      lcd.setCursor(0, 1);
      lcd.print("Retry in 5s");

      delay(5000);
    }
  }
}

// ================== setup ==================
void setup() {
  Serial.begin(115200);
  delay(1000);

  // I2C (SDA=D2, SCL=D1)
  Wire.begin(D2, D1);

  // LCD
  lcd.begin(16, 2);
  lcd.setRGB(0, 100, 255);

  lcd.clear();
  lcd.setCursor(0, 0);
  lcd.print("Booting...");

  hasBus108 = false;
  hasBus339 = false;
  lastZone  = -1;
  currentZone = 0;
  displayDirty = true;

  // Servo
  curtainServo.attach(SERVO_PIN, 500, 2500);
  curtainServo.write(0);
  currentServoAngle = 0;

  // WS2812 strip init: light first 25 LEDs
  strip.begin();
  strip.show();  // clear
  for (int i = 0; i < NUM_LEDS; i++) {
    // set to a medium brightness blue (you can change the color)
    strip.setPixelColor(i, strip.Color(0, 0, 150));
  }
  strip.show();

  // WiFi & MQTT
  setupWiFi();
  client.setServer(mqttServer, mqttPort);
  client.setCallback(mqttCallback);

  lcd.clear();
  lcd.setCursor(0, 0);
  lcd.print("WiFi OK");
  lcd.setCursor(0, 1);
  lcd.print(WiFi.localIP().toString());

  delay(1000);
  lcd.clear();
  lcd.setCursor(0, 0);
  lcd.print("Waiting 108/339");
}
// ================== LED animation state ==================
unsigned long ledTimer = 0;
int ledStep = 0;        
bool ledHold = false;    // 正在全亮停顿阶段

// ================== loop ==================
void loop() {
  if (!client.connected()) {
    reconnectMQTT();
  }
  client.loop();

  updateZoneFromRotary();

  if (displayDirty) {
    renderDisplay();
    displayDirty = false;
  }

  // ================== LED animation ==================
  unsigned long now = millis();

  // 如果正在全亮等待
  if (ledHold) {
    if (now >= ledTimer) {
      // 等待结束 → 全灭，然后重新开始流水
      for (int i = 0; i < NUM_LEDS; i++) {
        strip.setPixelColor(i, strip.Color(0, 0, 0));  
      }
      strip.show();
      ledStep = 0;
      ledHold = false;
      ledTimer = now + 80;  // 下一次点亮间隔
    }
    return; // 不继续执行流水逻辑
  }

  // 每 80ms 点亮下一颗灯
  if (now >= ledTimer) {
    ledTimer = now + 80;

    if (ledStep < NUM_LEDS) {
      // 点亮当前灯
      strip.setPixelColor(ledStep, strip.Color(0, 0, 150));  // 蓝色
      strip.show();
      ledStep++;

      // 如果到达最后一颗 → 进入 2 秒全亮阶段
      if (ledStep == NUM_LEDS) {
        ledHold = true;
        ledTimer = now + 2000; // 全亮停 2 秒
      }

    }
  }

  delay(10);
}

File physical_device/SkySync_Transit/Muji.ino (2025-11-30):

/*
  ESP8266 Departure Assistant - knob-route selection version
  - NodeMCU v3 (ESP8266)
  - MG90S servo on D5
  - Rotary Angle Sensor v1.2 SIG -> A0 (used to select route by position)
  - WS2812-like LED strip on D2 (KQB-4 treated as 5V addressable)
  - No physical display: display code commented out, Serial used as placeholder
  - Weather / Timetable / Bus API functions are placeholders (return mock data)
  - All comments and identifiers are English and detailed for collaborators

  How this works:
  - Turn the knob to select route: the analog range 0..1023 is split into ROUTE_COUNT bands.
    When the band (route index) changes the device will recompute recommended bus & UI.
  - Periodic full recompute also runs every MAIN_LOOP_INTERVAL_MS.
  - Replace the fetch*Placeholder functions with real HTTP+JSON code later.
*/

#include <Arduino.h>
#include <Servo.h>
#include <FastLED.h>
#include <time.h>
#include <vector>

// ----------------------------- Configurable constants -----------------------------
const uint8_t SERVO_PIN    = D5;   // MG90S signal pin
const uint8_t LED_PIN      = D2;   // data pin for WS2812-style strip
const uint16_t NUM_LEDS    = 24;   // set to number of LEDs you have
const uint8_t KNOB_PIN     = A0;   // rotary angle sensor SIG
const unsigned long MAIN_LOOP_INTERVAL_MS = 30UL * 1000UL; // periodic refresh interval
const int ROUTE_COUNT = 3; // number of routes selectable by knob

// Route names (for display / serial); change as you like
const char* ROUTES[ROUTE_COUNT] = {
  "Route A - 42",
  "Route B - 7",
  "Route C - Express"
};

// Servo params (MG90S typical)
Servo myServo;
const int SERVO_MIN_US = 500;
const int SERVO_MAX_US = 2500;

// LED
CRGB leds[NUM_LEDS];

// State / timing
int currentRouteIndex = 0;
int lastRouteIndex = -1; // initial force-update
unsigned long lastMainMs = 0;

// ----------------------------- Data structures -----------------------------
struct WeatherInfo {
  String condition; // e.g. "Clear", "Clouds", "Rain", "Thunderstorm"
  float tempC;
  int severity;     // 0..3
};

struct TimetableEntry {
  String title;
  time_t startEpoch; // epoch seconds
  int durationMin;
  String location;
};

struct BusOption {
  String routeName;
  time_t departureEpoch;
  int travelMin;
  String departureTimeStr; // e.g. "08:43"
  String remarks;
};

// runtime variables
WeatherInfo currentWeather;
TimetableEntry nextClass;
bool hasClass = false;
BusOption recommendedBus;
bool hasRecommendedBus = false;

// ----------------------------- Placeholder API functions (replace later) -----------------------------
// Keep these signatures; API team can replace internals with actual HTTP + JSON parsing.

WeatherInfo fetchWeatherPlaceholder() {
  // MOCK: return different weather depending on selected route for easy testing.
  WeatherInfo w;
  if (currentRouteIndex == 0) {
    w.condition = "Clear";
    w.tempC = 22.0;
    w.severity = 0;
  } else if (currentRouteIndex == 1) {
    w.condition = "Clouds";
    w.tempC = 16.0;
    w.severity = 1;
  } else {
    w.condition = "Rain";
    w.tempC = 8.5;
    w.severity = 2;
  }
  return w;
}

TimetableEntry fetchTimetablePlaceholder() {
  TimetableEntry t;
  time_t now = time(nullptr);
  // MOCK: next class 40 minutes from now
  t.title = "Math 101";
  t.startEpoch = now + 40 * 60;
  t.durationMin = 60;
  t.location = "Room A";
  return t;
}

std::vector<BusOption> fetchBusOptionsPlaceholder(const char* routeName, const TimetableEntry &target) {
  std::vector<BusOption> list;
  time_t now = time(nullptr);
  // MOCK: 3 upcoming departures spaced 7 minutes apart
  for (int i = 1; i <= 3; ++i) {
    BusOption b;
    b.routeName = String(routeName);
    b.departureEpoch = now + i * 7 * 60;
    b.travelMin = 20 + i*3; // arbitrary travel time
    struct tm tmStruct;
    gmtime_r(&b.departureEpoch, &tmStruct);
    char buf[8];
    strftime(buf, sizeof(buf), "%H:%M", &tmStruct);
    b.departureTimeStr = String(buf);
    b.remarks = "";
    list.push_back(b);
  }
  return list;
}

// ----------------------------- Mapping & helpers -----------------------------

// Map a weather condition to a base servo angle (degrees)
int weatherToBaseAngle(const WeatherInfo &w) {
  String s = w.condition;
  s.toLowerCase();
  if (s.indexOf("clear") >= 0 || s.indexOf("sun") >= 0) return 20;
  if (s.indexOf("cloud") >= 0) return 60;
  if (s.indexOf("rain") >= 0 || s.indexOf("drizzle") >= 0) return 110;
  if (s.indexOf("snow") >= 0) return 120;
  if (s.indexOf("thunder") >= 0 || w.severity >= 3) return 150;
  return 80;
}

// Convert minutes until departure into an angle offset (0..40)
int minutesToOffsetAngle(int minutesUntil) {
  if (minutesUntil < 0) minutesUntil = 0;
  if (minutesUntil > 120) minutesUntil = 120;
  return map(minutesUntil, 0, 120, 40, 0);
}

// Update servo: base (weather) + offset (minutes until)
void updateServoForSituation(const WeatherInfo &w, int minutesUntil) {
  int base = weatherToBaseAngle(w);
  int offset = minutesToOffsetAngle(minutesUntil);
  int finalAngle = base + offset;
  finalAngle = constrain(finalAngle, 0, 180);
  Serial.printf("[Servo] weather=%s severity=%d base=%d offset=%d -> angle=%d\n",
                w.condition.c_str(), w.severity, base, offset, finalAngle);
  myServo.write(finalAngle);
}

// LED urgency visualization: green/yellow/red+blink
void updateLEDsForUrgency(int minutesUntil) {
  if (minutesUntil < 0) minutesUntil = 0;
  if (minutesUntil > 120) minutesUntil = 120;

  CRGB color = CRGB::Green;
  bool blink = false;
  if (minutesUntil > 30) { color = CRGB::Green; blink = false; }
  else if (minutesUntil > 15) { color = CRGB::Yellow; blink = false; }
  else { color = CRGB::Red; blink = true; }

  static unsigned long lastToggle = 0;
  static bool onState = true;
  unsigned long now = millis();
  if (blink) {
    if (now - lastToggle > 500) {
      onState = !onState;
      lastToggle = now;
    }
  } else {
    onState = true;
  }

  for (uint16_t i = 0; i < NUM_LEDS; ++i) leds[i] = onState ? color : CRGB::Black;
  FastLED.show();
}

// Choose best bus: prefer earliest bus that arrives before class start minus buffer
bool chooseBestBus(const TimetableEntry &target, const std::vector<BusOption> &options, BusOption &out) {
  if (target.title.length() == 0 || options.size() == 0) return false;
  time_t classStart = target.startEpoch;
  const int arriveBufferMin = 5;
  bool found = false;
  time_t bestDeparture = 0;
  for (size_t i = 0; i < options.size(); ++i) {
    time_t arrival = options[i].departureEpoch + options[i].travelMin*60;
    if (arrival <= (classStart - arriveBufferMin*60)) {
      if (!found || options[i].departureEpoch < bestDeparture) {
        found = true;
        bestDeparture = options[i].departureEpoch;
        out = options[i];
      }
    }
  }
  if (!found) { out = options[0]; found = true; } // fallback earliest
  return found;
}
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

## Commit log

2025-11-25 Add meeting Minutes (25-Nov-2025)
    Documented meeting minutes for the transport project, outlining themes, physical device components, digital twin screens, and work distribution.
2025-11-30 Add tests for sensors
    Initial ESP8266 hardware test for MG90S servo, rotary angle sensor, and BTF 5V 60LED/m strip: sweep servo 0–180°, read knob on A0 via serial, and drive the LED strip with color changes based on knob 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
2025-11-30 Add 1st version of SkySync Transit
    Including servo, knob-based route selection, LED urgency display, and placeholder APIs (weather/timetable/bus) with serial output for display.
2025-12-06 Add the physical model
    [Cover.stl, Fix.stl, OPS (1).stl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]
2025-12-06 Add the Model of the car
    [car Model.3mf]
2025-12-10 Add digital models
    [DigitalCar.blend]
2026-01-09 Add README for SkySync_Transit project
    Added detailed project documentation for SkySync_Transit, including sections on project rationale, system overview, device design, software technologies, contributions, evaluation, future improvement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
2026-01-11 Revise README for SkySync_Transit project clarity
    Refined project context and motivation for SkySync_Transit. Updated sections on physical device design and data visualization logic for clarity and coherence.
2026-01-11 Enhance README with Digital Twin and AR details
    Expanded the README to include detailed sections on Digital Twin Interface, Physical Device Synchronisation, and Image Recognition, providing insights into UI implementation and AR functionality.
2026-01-11 Revise system overview in README.md
    Updated the README to clarify the system overview and design concept for both the physical device and the digital twin system.
2026-01-11 Refine 3D-printed structure and gauge panel description
    Revised the description of the 3D-printed structure and gauge panel for clarity and conciseness.
2026-01-11 Enhance README with detailed structure and gauge panel info
    Updated the description of the 3D-printed structure and gauge panel, adding details about spatial accuracy and sensor placement.
